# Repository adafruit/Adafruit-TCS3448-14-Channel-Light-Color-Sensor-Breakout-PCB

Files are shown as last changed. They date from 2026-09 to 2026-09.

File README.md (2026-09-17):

## Adafruit TCS3448 14-Channel Light / Color Sensor Breakout - STEMMA QT / Qwiic PCB

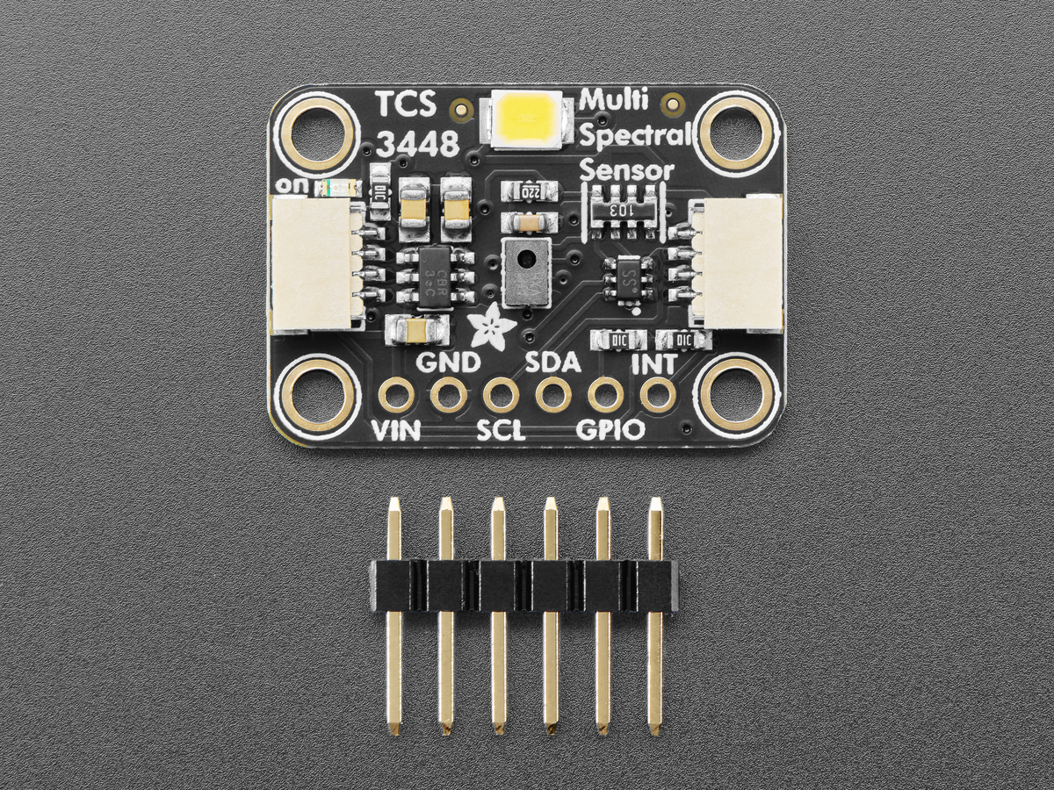
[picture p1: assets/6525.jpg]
<a href="http://www.adafruit.com/products/6525"><br/>
Click here to purchase one from the Adafruit shop</a>

PCB files for the Adafruit TCS3448 14-Channel Light / Color Sensor Breakout - STEMMA QT / Qwiic. 

Format is EagleCAD schematic and board layout
* https://www.adafruit.com/product/6525

### Description

The <b>Adafruit TCS3448 (a.k.a TCS34488) Multi-Spectral Sensor</b> is a multi-channel spectrometer, which is a special type of light sensor that is able to detect not only the amount of light present but also the amounts of light within different wavelengths. This means that you can use it to detect much better than the human eye is capable of, what color or colors of light is present.

The TCS3448 packs within its 3x2mm footprint 25 photodiodes that can detect 11 separate, overlapping bands of visible light, plus one near infrared, one clear and a flicker channel for 14 channels total. Compared to the AS7341, this sensor has 4 more light channels - but you'll need to use a new firmware driver since it's not back-compatible.

<b>The TCS3448 is ams Osram's 'refresh' of the AS7343</b>, so it's an upgrade from the AS7341 and has some slight improvements/changes over the AS7343: 

* I2C address changed from 0x39 to 0x59.
* Retuned optical filters: channel centers move by a few nanometers and several visible channels have higher responsivity especially violet/blue and the F8 far-red channel.
* Sensitivity is not higher everywhere; NIR response is lower.
* Firmware is not 100% drop-in! You'll need to recompile since the I2C address has changed

The multi-spectral color measuring capabilities of the TCS3448 can be used to quantify the specific makeup of light, either emitted or reflective. It's kind of like a mini spectroscopy sensor. This is possible thanks to the impressive collection of sensors in the TCS3448 being routed through 6 independent 16-bit ADCs that take the raw measurements and convert them to digital values that can be read out over I2C.

14 readable individual sensor elements (13 light channels plus flicker detection) don’t exactly fit through a 6-channel ADC all at once, so the chip includes a so-called Super MUX (SMUX) that allows you to route the signal from any sensor to any ADC channel. The sensor also has GPIO and interrupt pins that can allow it to communicate directly with other sensors, or the microcontroller itself.

All of this capability is made accessible by mounting the sensor on a STEMMA QT form factor breakout board, complete with level shifting circuitry and [SparkFun Qwiic](https://www.sparkfun.com/qwiic) compatible [Stemma QT](https://learn.adafruit.com/introducing-adafruit-stemma-qt) connectors. This means that you can, without needing to solder, connect our TCS3448 breakout into your 3.3V or 5V microcontroller of choice be it an Arduino Uno, Raspberry Pi, or one of the many [CircuitPython-compatible boards](https://circuitpython.org/downloads). While it certainly takes a bit of work to make all those different light sensors share their measurements, our Arduino and CircuitPython libraries take care of all of that hard work for you and even include example code to help get you started. [QT Cable is not included, but we have a variety in the shop](https://www.adafruit.com/?q=stemma+qt+cable&sort=BestMatch).

### License

Adafruit invests time and resources providing this open source design, please support Adafruit and open-source hardware by purchasing products from [Adafruit](https://www.adafruit.com)!

Designed by Limor Fried/Ladyada for Adafruit Industries.

Creative Commons Attribution/Share-Alike, all text above must be included in any redistribution. 
See license.txt for additional details.

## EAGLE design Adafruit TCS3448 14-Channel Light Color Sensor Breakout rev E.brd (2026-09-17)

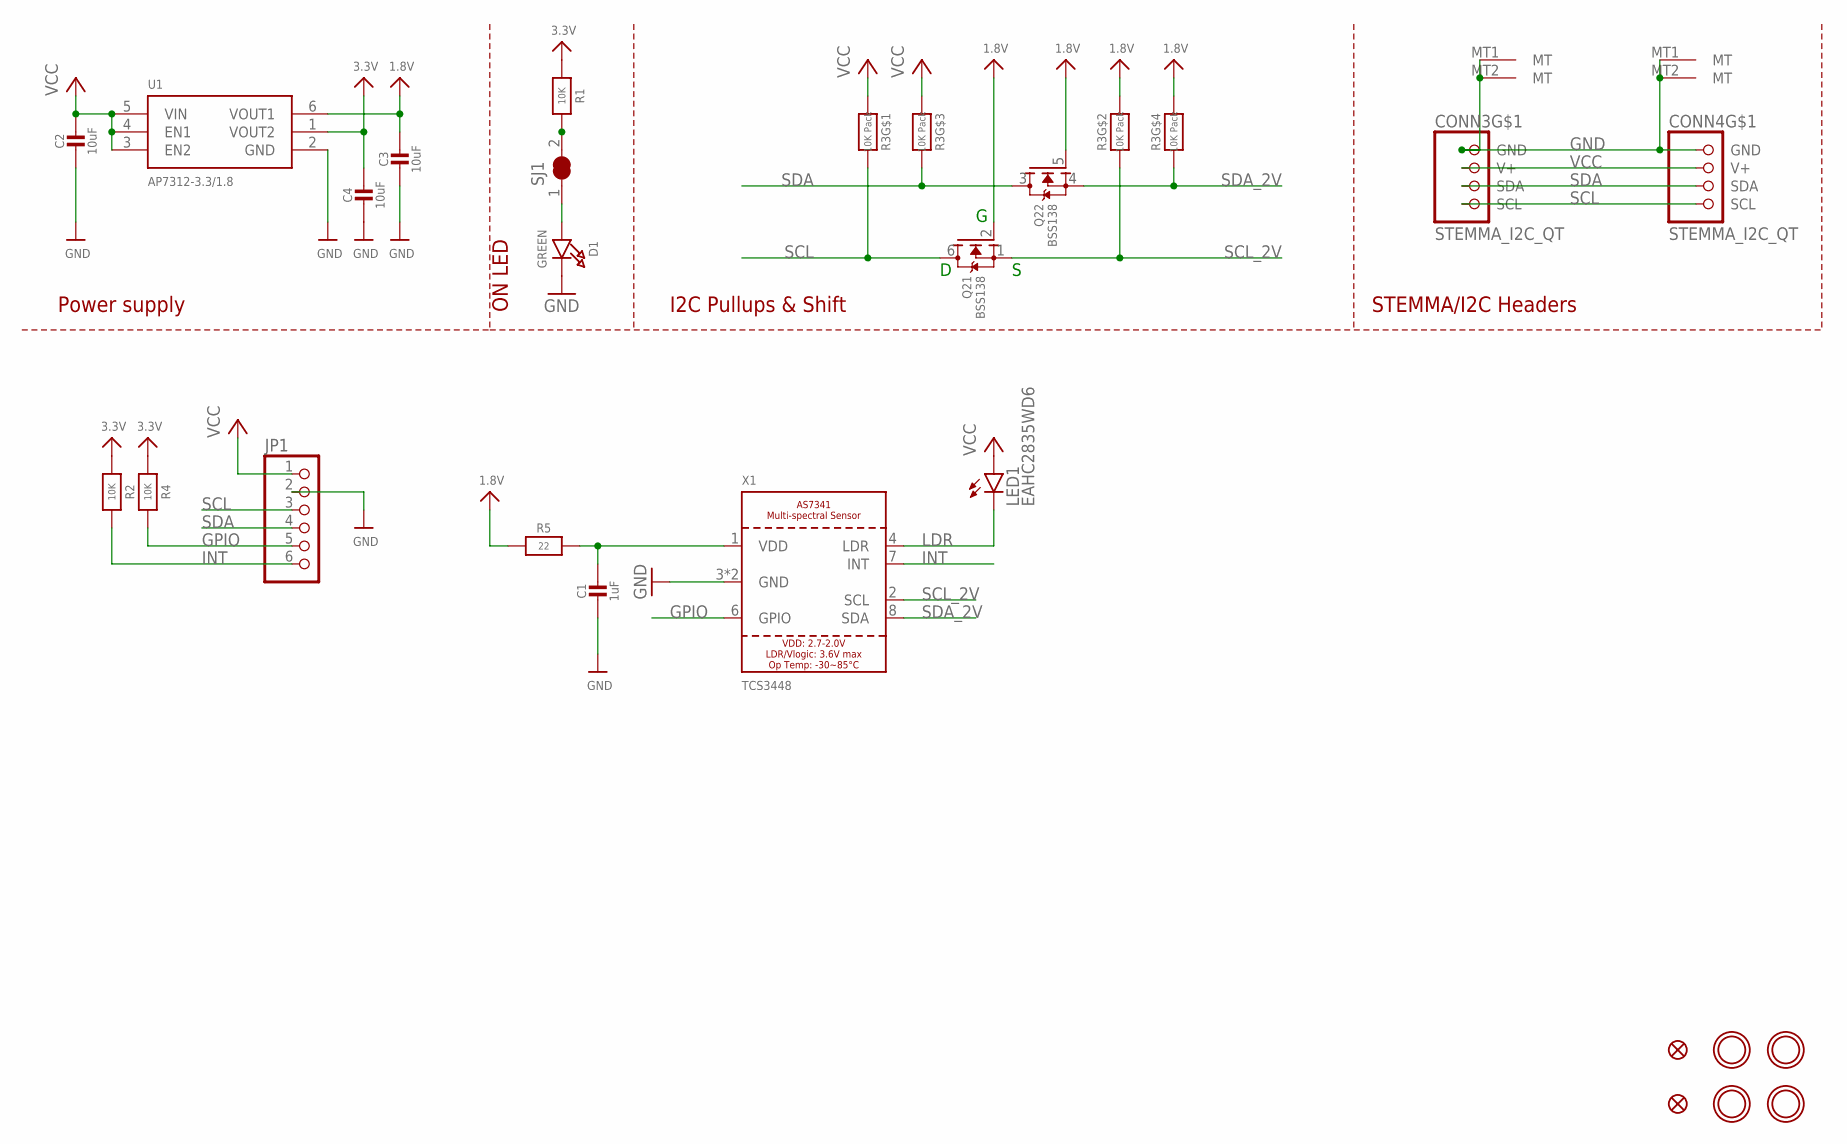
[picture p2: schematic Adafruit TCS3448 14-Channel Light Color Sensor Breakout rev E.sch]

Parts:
C1: 1uF; 0603-NO
C2, C3, C4: 10uF; 0805-NO
CONN3, CONN4: STEMMA_I2C_QT; JST_SH4
D1: GREEN; CHIPLED_0603_NOOUTLINE
FID3, FID4: FIDUCIAL_0.5MM
JP1: HEADER-1X670MIL; 1X06_ROUND_70
LED1: EAHC2835WD6; KA-3528ASYC
Q2: BSS138; SOT363
R1, R2, R4: 10K; 0603-NO
R3: 10K Pack; RESPACK_4X0603
R5: 22; 0603-NO
SJ1: SOLDERJUMPER_CLOSED; SOLDERJUMPER_CLOSEDWIRE
U1: AP7312-3.3/1.8; SOT23-6
U$1, U$17, U$19, U$21: MOUNTINGHOLE2.5; MOUNTINGHOLE_2.5_PLATED
X1: TCS3448; AS7341

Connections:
1.8V: C3.1, Q2.2 (G), Q2.5 (G), R3.2 (1), R3.4 (1), R5.1, U1.6 (VOUT1)
3.3V: C4.1, R1.1, R2.1, R4.1, U1.1 (VOUT2)
GND: C1.2, C2.2, C3.2, C4.2, CONN3.1 (GND), CONN3.MT1 (MT), CONN3.MT2 (MT), CONN4.1 (GND), CONN4.MT1 (MT), CONN4.MT2 (MT), D1.C, JP1.2, U1.2 (GND), X1.3 (GND), X1.5 (GND)
GPIO: JP1.5, R4.2, X1.6 (GPIO)
INT: JP1.6, R2.2, X1.7 (INT)
LDR: LED1.C, X1.4 (LDR)
unnamed: D1.A, SJ1.1
unnamed: R1.2, SJ1.2
unnamed: C1.1, R5.2, X1.1 (VDD)
SCL: CONN3.4 (SCL), CONN4.4 (SCL), JP1.3, Q2.6 (D), R3.8 (2)
SCL_2V: Q2.1 (S), R3.7 (2), X1.2 (SCL)
SDA: CONN3.3 (SDA), CONN4.3 (SDA), JP1.4, Q2.3 (D), R3.6 (2)
SDA_2V: Q2.4 (S), R3.5 (2), X1.8 (SDA)
VCC: C2.1, CONN3.2 (V+), CONN4.2 (V+), JP1.1, LED1.A, R3.1, R3.3 (1), U1.3 (EN2), U1.4 (EN1), U1.5 (VIN)

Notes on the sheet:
I2C Pullups & Shift
STEMMA/I2C Headers
ON LED
Power supply

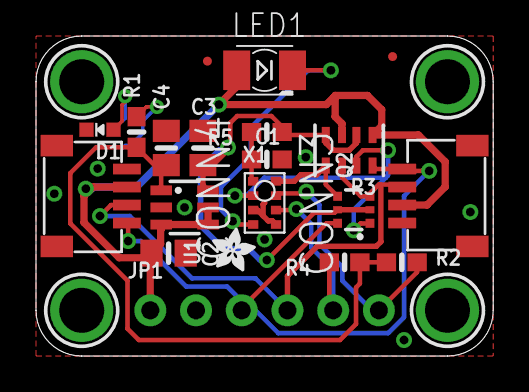
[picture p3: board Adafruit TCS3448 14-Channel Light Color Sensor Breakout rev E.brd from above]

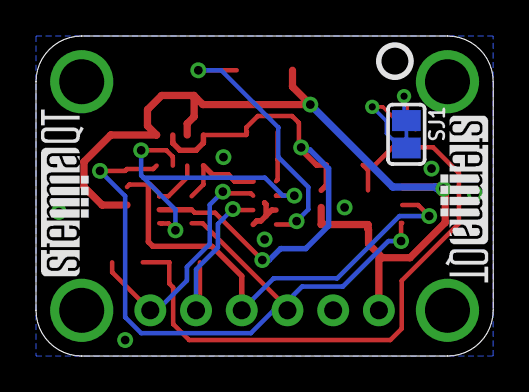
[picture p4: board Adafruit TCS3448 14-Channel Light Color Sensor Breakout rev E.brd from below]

Board: 2 copper layers, 25.4 x 17.8 mm, 44 parts (10 on the bottom side), 14 nets.

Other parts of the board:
PLABEL0: PLABEL0
PLABEL1: PLABEL1
PLABEL2: PLABEL2
PLABEL3: PLABEL3
PLABEL4: PLABEL4
PLABEL5: PLABEL5
PLABEL8: PLABEL8
PLABEL11: PLABEL11
PLABEL14: PLABEL14
PLABEL15: PLABEL15
PLABEL18: PLABEL18
PLABEL19: PLABEL19
PLABEL20: PLABEL20
PLABEL21: PLABEL21
PLABEL22: PLABEL22
PLABEL23: PLABEL23
U$16: ADAFRUIT_2.5MM
U$25: PCBFEAT-REV-040
U$30, U$31: STEMMAQT

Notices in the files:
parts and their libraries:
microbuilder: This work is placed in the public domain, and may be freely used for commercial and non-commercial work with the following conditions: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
